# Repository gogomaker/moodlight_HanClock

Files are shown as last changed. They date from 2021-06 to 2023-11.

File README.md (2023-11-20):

# moodlight_HanClock
와디즈에 펀딩되었던 얘쁜 한글시계 따라 만들기

# 제작동기

참 구글이란 게 신기하다. 내가 한글시계 만들겠다고 온 구글(?)에 설쳐 다니다 보니, 와디즈에서 펀딩 진행했었던 아름다운 시계를 뙇 하고 보여주는 것이 아닌가.

나란 사람. 수학적이지만(?) 갬성 있는 사람.

참지 못하고 구매하려 하였으나 파는 곳이 없어 직접 만들기로 한다...

# 제작일기
2021-02-27: 아름다움에 이끌리어 제작을 시작하였다.

2021-04-14: 그 이후로 바뻐서 작업 못 하다가 다시 시작함

2021-06-15: 컴파일 에러 수정 

2021-06-18: 오늘은 LED관련 제어 함수를 생성하였다. 요즘 따라 작업이 아주 잘 된다.

2021-06-19: 오늘은 LED관련 제어 함수를 모두 완성하였다. 
실제로 실행하였을 때는 제대로 동작하지 않는 부분이 있을 것 같다만, 
논리적으로는 없는 것 같다. 또한, 코드 설명 주석을 수정하였고, LED의 delay 를 제외하고는
모두 다 완성하였다.

2021-06-20: 오늘은 프로그램을 완성하였다. 그리고 PCB설계의 엄청난 에러를 수정하였다.
우선, 프로그램은 기존에 있던 코드를 읽기 좋게 다듬고, 몇가지 변수를 추가하고, 코드를 정돈하였다.
또한, PCB설계에서 LED의 극을 잘못 설정해 놓았었기에, 이 또한 수정하였고,
'시' LED의 (-) 극을 digital pin이 아닌 ground로 바로 연결하였다.(이에 맞게 프로그램도 수정하였다)

2021-06-24: 오늘은 내 옛 노트북을 사용할 수 있게 설정한다고 바뻤다. 
오늘, 옛 노트북에 이 프로젝트를 연동시켜 놓았다.
앞으로는, git push뿐 아니라 git pull도 잘 연습할 수 있을 것 같다.

2021-07-15: 오늘은 시계를 어떻게 만들지, 특히 회로에 대한 부분을 전체적으로 점검했다.

2023-11-20: 오랜만에 (무려 2년만에!) 다시 돌아왔다. 
이제 다시 이 시계를 살려보려 한다. \
아마 디자인을 완전히 갈아엎고 시작할 듯 하다.

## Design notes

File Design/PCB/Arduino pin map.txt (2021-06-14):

Arduino pin map

 3 - LED
 4 - hour LED
 5 - LED
 6 - LED
 9 - LED
10 - LED
11 - LED
12 - SW_MIN
13 - SW_HOUR
A0 - brightness_LED

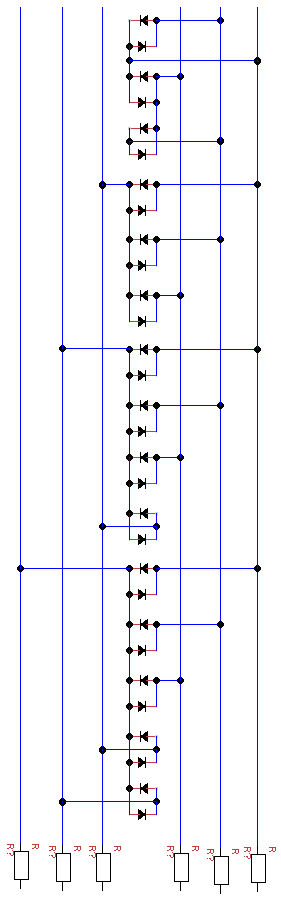
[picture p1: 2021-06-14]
Design/PCB/charie_30pins.png

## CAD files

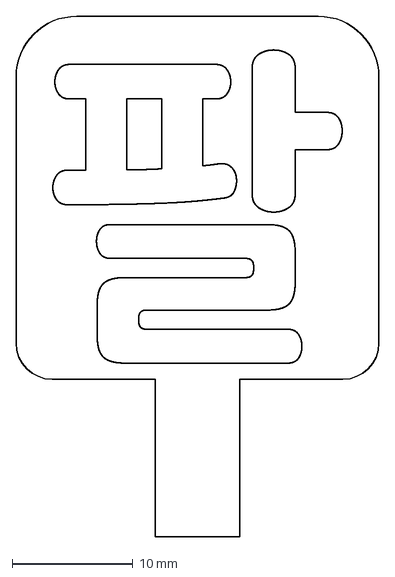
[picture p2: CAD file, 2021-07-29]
Design/External design/acrylic/팔.dxf
30.0 x 43.0 mm

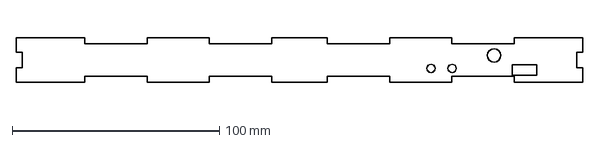
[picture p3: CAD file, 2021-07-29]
Design/External design/back.dxf
273.2 x 21.5 mm

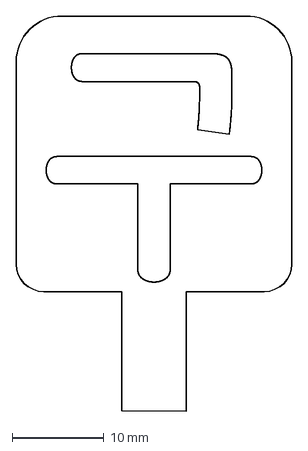
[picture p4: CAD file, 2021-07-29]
Design/External design/acrylic/구.dxf
30.0 x 43.0 mm

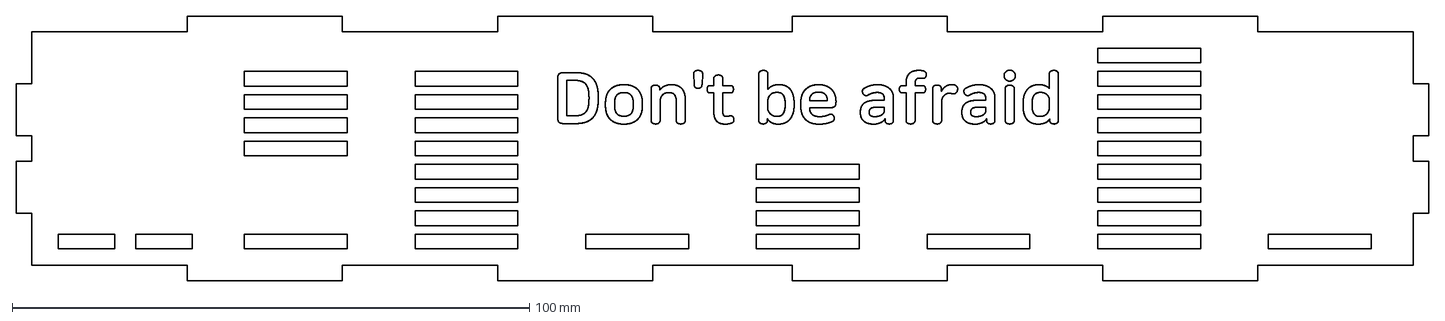
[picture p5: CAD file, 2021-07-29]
Design/External design/top.dxf
273.2 x 51.2 mm

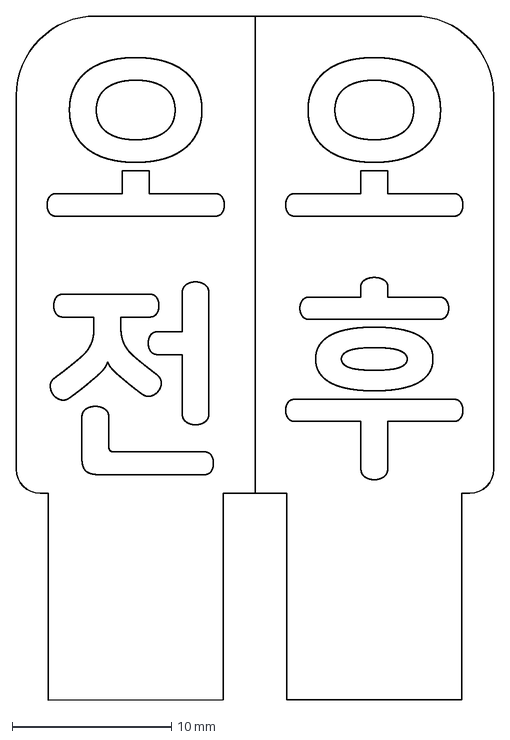
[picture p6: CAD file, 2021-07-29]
Design/External design/acrylic/오전오후.dxf
30.0 x 43.0 mm

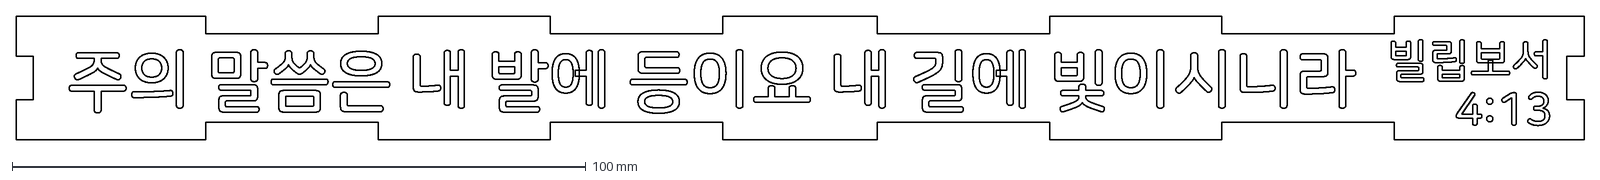
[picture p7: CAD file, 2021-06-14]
Design/External design/front.dxf
273.2 x 21.5 mm

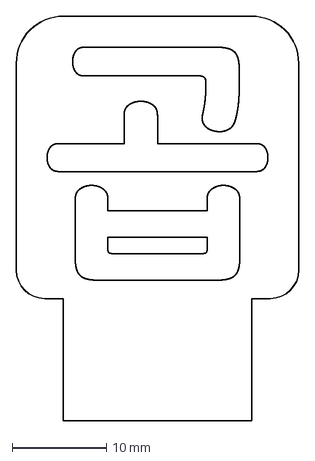
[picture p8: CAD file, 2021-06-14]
Design/External design/acrylic/곱.dxf
30.0 x 43.0 mm

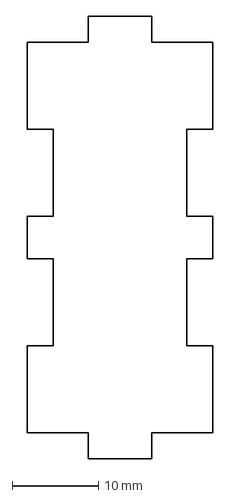
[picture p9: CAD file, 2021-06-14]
Design/External design/side.dxf
21.5 x 51.2 mm

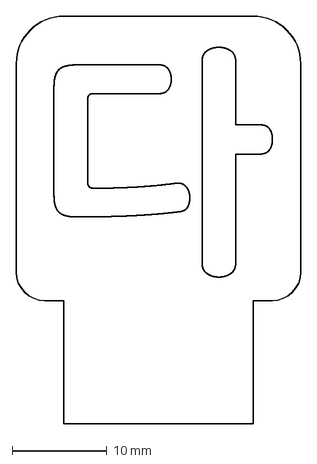
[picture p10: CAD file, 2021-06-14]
Design/External design/acrylic/다.dxf
30.0 x 43.0 mm

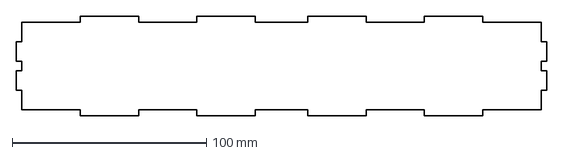
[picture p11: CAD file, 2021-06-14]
Design/External design/base.dxf
273.2 x 51.2 mm

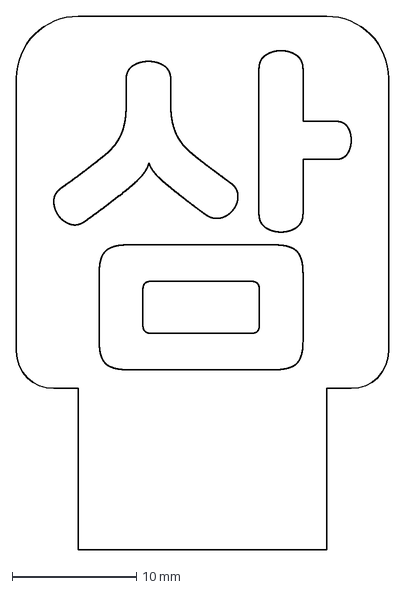
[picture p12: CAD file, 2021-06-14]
Design/External design/acrylic/삼_3.dxf
30.0 x 43.0 mm

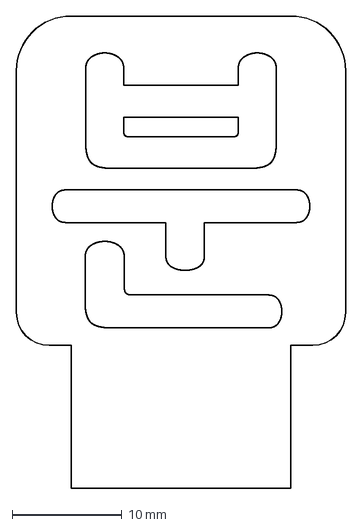
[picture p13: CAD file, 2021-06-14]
Design/External design/acrylic/분.dxf
30.0 x 43.0 mm

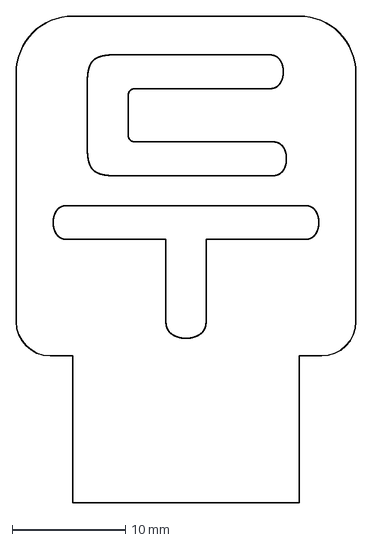
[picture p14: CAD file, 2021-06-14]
Design/External design/acrylic/두.dxf
30.0 x 43.0 mm

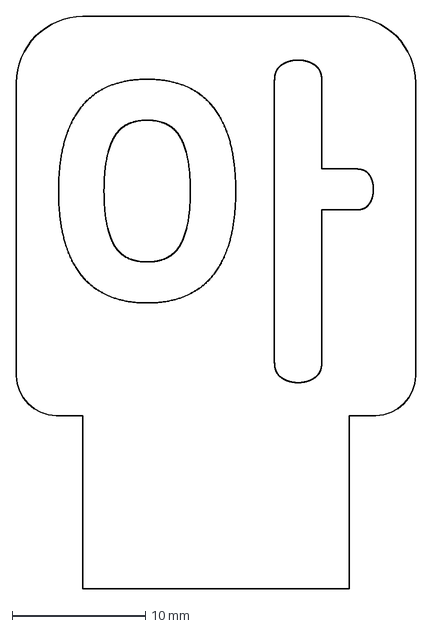
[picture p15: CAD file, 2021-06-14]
Design/External design/acrylic/아.dxf
30.0 x 43.0 mm

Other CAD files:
Design/External design/acrylic/덟.dxf
Design/External design/acrylic/시.dxf
Design/External design/acrylic/삼.dxf
Design/External design/acrylic/한.dxf
Design/External design/acrylic/네.dxf
Design/External design/acrylic/사.dxf
Design/External design/acrylic/사_4.dxf
Design/External design/acrylic/섯.dxf
Design/External design/acrylic/세.dxf
Design/External design/acrylic/십_2.dxf
Design/External design/acrylic/여.dxf
Design/External design/acrylic/열.dxf
Design/External design/acrylic/오.dxf
Design/External design/acrylic/오_2.dxf
Design/External design/acrylic/육.dxf
Design/External design/acrylic/이.dxf
Design/External design/acrylic/이_2.dxf
Design/External design/acrylic/일.dxf
Design/External design/acrylic/일_2.dxf
Design/External design/acrylic/칠.dxf
Design/External design/acrylic/홉.dxf

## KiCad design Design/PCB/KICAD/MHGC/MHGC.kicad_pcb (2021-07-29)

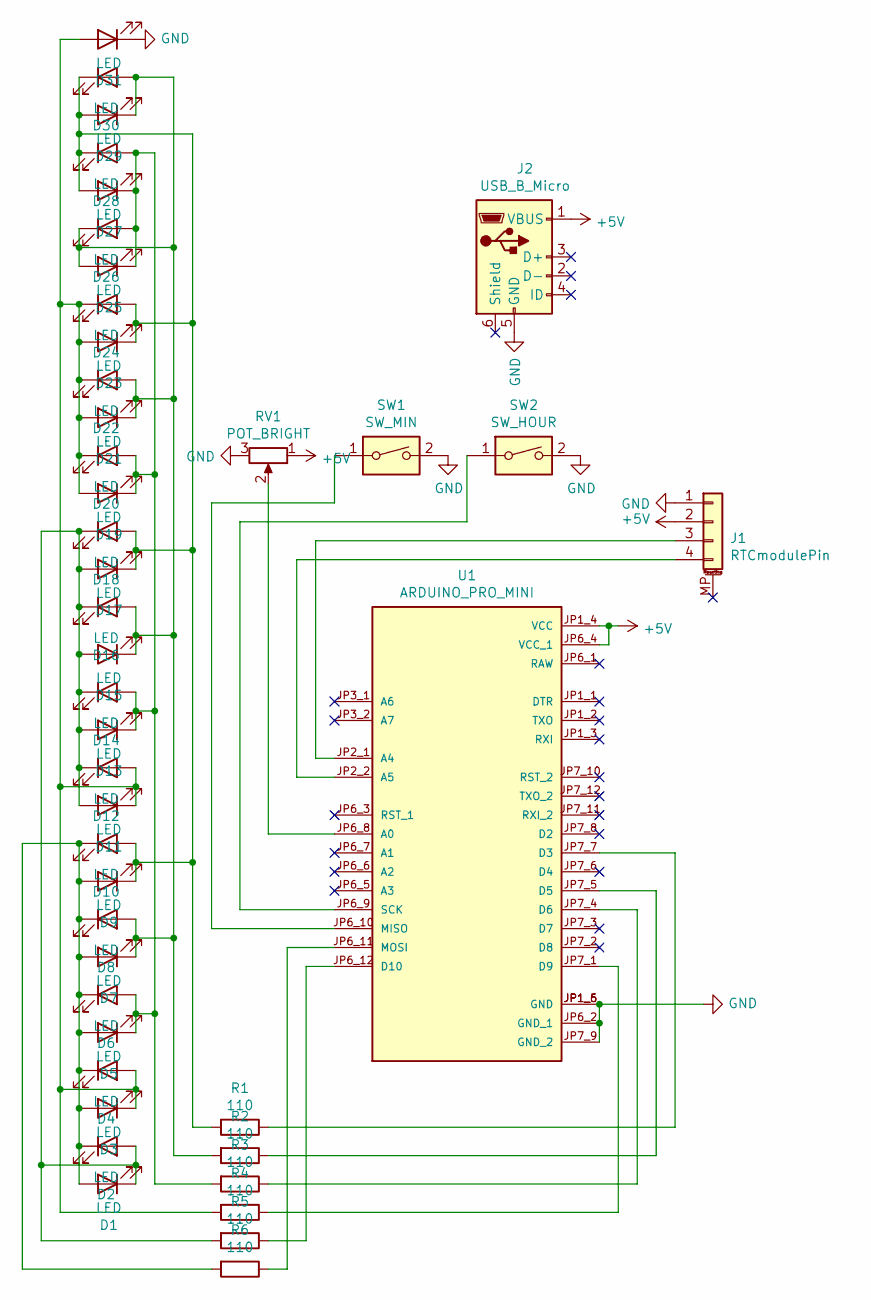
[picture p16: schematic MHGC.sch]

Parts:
D1, D2, D3, D4, D5, D6, D7, D8, D9, D10, D11, D12, D13, D14, D15, D16, D17, D18, D19, D20, D21, D22, D23, D24, D25, D26, D27, D28, D29, D30, D31: LED; 3216LED
J1: RTCmodulePin; PinSocket_1x04_P2.54mm_Vertical
J2: USB_B_Micro; USB_Micro-B_Amphenol_10118194_Horizontal
R1, R2, R3, R4, R5, R6: 110; 3216R
RV1: POT_BRIGHT
SW1: SW_MIN; KLT_SW
SW2: SW_HOUR; KLT_SW
U1: ARDUINO_PRO_MINI; MODULE_ARDUINO_PRO_MINI; PARTREV N/A

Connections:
+5V: J1.2, J2.1 (VBUS), RV1.1, U1.JP1_4 (VCC), U1.JP6_4 (VCC_1)
GND: D31.1 (K), J1.1, J2.5 (GND), RV1.3, SW1.2, SW2.2, U1.JP1_5 (GND), U1.JP1_6 (GND), U1.JP6_2 (GND_1), U1.JP7_9 (GND_2)
unnamed: D1.1 (K), D2.2 (A), D11.2 (A), D12.1 (K), D13.2 (A), D14.1 (K), D15.2 (A), D16.1 (K), D17.2 (A), D18.1 (K), R5.2
unnamed: D1.2 (A), D2.1 (K), D3.2 (A), D4.1 (K), D5.2 (A), D6.1 (K), D7.2 (A), D8.1 (K), D9.2 (A), D10.1 (K), R6.2
unnamed: D9.1 (K), D10.2 (A), D17.1 (K), D18.2 (A), D23.1 (K), D24.2 (A), D27.2 (A), D28.1 (K), D29.2 (A), D30.1 (K), R1.2
unnamed: D3.1 (K), D4.2 (A), D11.1 (K), D12.2 (A), D19.2 (A), D20.1 (K), D21.2 (A), D22.1 (K), D23.2 (A), D24.1 (K), D31.2 (A), R4.2
unnamed: D5.1 (K), D6.2 (A), D13.1 (K), D14.2 (A), D19.1 (K), D20.2 (A), D25.1 (K), D26.2 (A), D27.1 (K), D28.2 (A), R3.2
unnamed: D7.1 (K), D8.2 (A), D15.1 (K), D16.2 (A), D21.1 (K), D22.2 (A), D25.2 (A), D26.1 (K), D29.1 (K), D30.2 (A), R2.2
unnamed: J1.3, U1.JP2_1 (A4)
unnamed: J1.4, U1.JP2_2 (A5)
unnamed: R1.1, U1.JP7_7 (D3)
unnamed: R2.1, U1.JP7_5 (D5)
unnamed: R3.1, U1.JP7_4 (D6)
unnamed: R4.1, U1.JP7_1 (D9)
unnamed: R5.1, U1.JP6_12 (D10)
unnamed: R6.1, U1.JP6_11 (MOSI)
unnamed: RV1.2, U1.JP6_8 (A0)
unnamed: SW1.1, U1.JP6_10 (MISO)
unnamed: SW2.1, U1.JP6_9 (SCK)

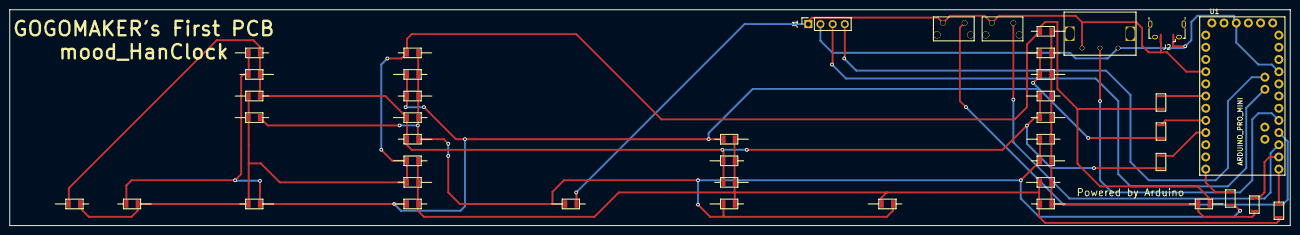
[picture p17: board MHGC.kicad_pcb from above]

Board: 2 copper layers, 267.0 x 45.0 mm, 43 parts (0 on the bottom side), 19 nets.

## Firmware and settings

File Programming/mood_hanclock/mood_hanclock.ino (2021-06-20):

/* mood_hanclock.ino
  Name:   Moodlight_HangeulClock
  Owner:  gogomaker
  Create: 2021-05-14, 5:26 PM

Project introduction_
  This .ino file is very important. Because it's me.

Project TODO

이 프로젝트는, 한글시계 프로그램과 매우 유사하게 제작 될 것이다.
다만 다른 것은 하나, 시간의 표기 방식(사실 날로먹기지 ㅋ)
그렇기에, 기존 한글시계 프로그램의 틀을 거의 가져와서 시간 표시하는 부분만 바꾸면 된다.

수정사안: 
이 시계는 버튼이 2개 들어간다. 그리고 각 버튼이 시간 및 분을 조정하는 데 사용이 된다.
버튼이 길게(1200ms) 눌렸을 때, 시간 또는 분이 증가한다.
또한, 짧은 시간에 대해 처리하는 if문을 날려야 한다.
*/
/* Arduino pin map
  3 - LED
  4 - LED(hour)
  5 - LED
  6 - LED
  9 - LED
 10 - LED
 11 - LED
 12 - SW_MIN
 13 - SW_HOUR
 A0 - brightness_potentiometers

 buttons will connection INPUT_PULLUP.
*/
/* LED pin map
  LED array
  PIN	  0	 1	2	3	4	5
  ARDU	11 10	9	6	5	3
*/

#include "src/functions.h"

//Charlie plexing mapping
byte pair[31][2] = // {LED(+) pin ,LED(-) pin}
{
  {LED_4,LED_5},  //PM
  {LED_5,LED_4},  //AM
  {LED_1,4    },  //hour
  {LED_1,LED_0},  //MIN
  {LED_1,LED_5},  //H_1
  {LED_5,LED_1},  //H_2
  {LED_2,LED_3},  //H_3
  {LED_3,LED_2},  //H_4
  {LED_3,LED_4},  //H_5_F
  {LED_5,LED_3},  //H_6_F
  {LED_3,LED_5},  //H_7_F
  {LED_0,LED_1},  //h_9_F
  {LED_2,LED_4},  //H_5_L
  {LED_2,LED_5},  //H_7_L
  {LED_4,LED_2},  //H_8_L
  {LED_5,LED_2},  //H_9_L
  {LED_4,LED_3},  //H_TEN
  {LED_0,LED_2},  //M_1
  {LED_2,LED_0},  //M_2
  {LED_0,LED_3},  //M_3
  {LED_3,LED_0},  //M_4
  {LED_0,LED_4},  //M_5
  {LED_4,LED_0},  //M_6
  {LED_0,LED_5},  //M_7
  {LED_5,LED_0},  //M_8
  {LED_1,LED_2},  //M_9
  {LED_2,LED_1},  //M_10
  {LED_1,LED_3},  //M_20
  {LED_3,LED_1},  //M_30
  {LED_1,LED_4},  //M_40
  {LED_4,LED_1},  //M_50
};

//declaration variable
extern volatile unsigned long timer0_millis; //millis 오버플로우 대비 초기화
unsigned long time = 0;
byte sec, lastSec = 0;
byte hourPlus, minPlus = 0; //버튼이 눌릴 때 이곳에 값이 임시저장 됨
byte minRtc, hourRtc = 0; //RTC의 시간값이 저장됨
byte min, hour = 0;   //최종적으로 출력되는 시간값이 저장됨
bool isResetMillis = false;
byte bright = 0;  //255가 최대, 0이 최소, 가변저항 제어

byte tMSB, tLSB;  //RTC온도관련
float temp3231;

unsigned long bu_led_w = 0;
bool ledCheck = false;

bool bu_reading[2] = { HIGH, HIGH };  //버튼의 실제 상태를 표현하는 변수
bool bu_state[2] = { HIGH, HIGH };  //체터링을 거른 버튼의 상태를 표현하는 변수
bool last_bu_state[2] = { HIGH, HIGH }; //마지막 버튼 상태
unsigned long LastDebounceTime[2] = {0, 0};

unsigned long bu_t_w, last_bu_t_w = 0;  //시 버튼이 언제 눌렸는가
unsigned long bu_m_w, last_bu_m_w = 0;  //분 버튼이 언제 눌렸는가
unsigned long wait_t, wait_m = 0; //LED깜박일 때 사용
bool isblinkH, isblinkM = false;

void setup() {
  Serial.begin(115200);
  Serial.println("Mood Light Hangeul Clock is turning ON");
  Serial.println("Clock start");
  //bright setting
  bright = map(analogRead(CONTROL_BRIGHT), 0, 1023, 0, BRIGHT_LIMIT);
  //button setting
  pinMode(BU_MIN, INPUT_PULLUP);
  pinMode(BU_HOUR, INPUT_PULLUP);
  //LED pins setting
  pinMode(LED_0, OUTPUT);
  pinMode(LED_1, OUTPUT);
  pinMode(LED_2, OUTPUT);
  pinMode(LED_3, OUTPUT);
  pinMode(LED_4, OUTPUT);
  pinMode(LED_5, OUTPUT);
}

void loop() {
  time = millis();
  bright = map(analogRead(CONTROL_BRIGHT), 0, 1023, 0, BRIGHT_LIMIT);
  get3231Date();
  if (!sec && !minRtc && !hourRtc) {	//millis 초기화
		if(!timer0_millis) isResetMillis = true;
		if (isResetMillis == true) {
			//Serial.println("Timer reset");
			bu_led_w = 0;
			LastDebounceTime[0] = 0;
			LastDebounceTime[1] = 0;
			bu_t_w = 0;
			last_bu_t_w = 0;
			wait_t = 0;
			wait_m = 0;
			time = 0;
			timer0_millis = 0;
			isResetMillis = false;
		}
	}
  
  //매 초마다
  if (sec != lastSec) {
    hour = (hourRtc + hourPlus) % 24;
    min = (minRtc + minPlus) % 60;
    if (!sec) {	//매 0초마다(1분 간격으로)
      if (hourPlus || minPlus) {  //RTC값 동기화
      //Serial.println("RTC set");
      set3231Date();
      }
      //Serial.println("updated");
    }
    lastSec = sec;
  }
  displayTime(hour, min); //시간출력, 계속 돌려야 하기에 loop에 넣었다
  
  //button
  void changeHour();
  void changeMin();
}

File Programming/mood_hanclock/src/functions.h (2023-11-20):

#ifndef __FUNCTIONS_H__
# define __FUNCTIONS_H__

#include <Arduino.h>
#include <Wire.h>

//define pin map
#define LED_0 11
#define LED_1 10
#define LED_2 9
#define LED_3 6
#define LED_4 5   
#define LED_5 3
#define BU_MIN 12
#define BU_HOUR 13
#define CONTROL_BRIGHT A0
//define LED numbers
#define LED_PM 0
#define LED_AM 1
#define LED_HOUR 2
#define LED_MIN 3
#define LED_H_1 4
#define LED_H_2 5
#define LED_H_3 6
#define LED_H_4 7
#define LED_H_5_F 8
#define LED_H_6_F 9
#define LED_H_7_F 10
#define LED_H_8_F 9
#define LED_H_9_F 11
#define LED_H_5_L 12
#define LED_H_6_L 12
#define LED_H_7_L 13
#define LED_H_8_L 14
#define LED_H_9_L 15
#define LED_H_TEN 16
#define LED_M_1 17
#define LED_M_2 18
#define LED_M_3 19
#define LED_M_4 20
#define LED_M_5 21
#define LED_M_6 22
#define LED_M_7 23
#define LED_M_8 24
#define LED_M_9 25
#define LED_M_10 26
#define LED_M_20 27
#define LED_M_30 28
#define LED_M_40 29
#define LED_M_50 30
//define other...
#define DS3231_I2C_ADDRESS 104
#define FLICKER_TIME 5  //LED flicker ms
#define debounceDelay 50  //button debounce removal delay
#define bu_interval 1200
#define BRIGHT_LIMIT 250
#define LED_DELAY 2

extern byte pair[31][2];
extern unsigned long time;
extern byte sec, lastSec;
extern byte hourPlus, minPlus; //버튼이 눌릴 때 이곳에 값이 임시저장 됨
extern byte minRtc, hourRtc; //RTC의 시간값이 저장됨
extern byte min, hour;   //최종적으로 출력되는 시간값이 저장됨
extern bool isResetMillis;
extern byte bright;  //255가 최대, 0이 최소, 가변저항 제어
extern byte tMSB, tLSB;  //RTC온도관련
extern float temp3231;
extern bool bu_reading[2];  //버튼의 실제 상태를 표현하는 변수
extern bool bu_state[2];  //체터링을 거른 버튼의 상태를 표현하는 변수
extern bool last_bu_state[2]; //마지막 버튼 상태
extern unsigned long LastDebounceTime[2];
extern unsigned long bu_t_w, last_bu_t_w;  //시 버튼이 언제 눌렸는가
extern unsigned long bu_m_w, last_bu_m_w;  //분 버튼이 언제 눌렸는가

void clearLED();
int turnOnLED(int n);
int displayTime(int h, int m);
void changeHour();
void changeMin();
byte decToBcd(byte val);
void set3231Date();
void get3231Date();
float get3231Temp();
void showSerialTime();

#endif

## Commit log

2021-06-14 Headerfile complited 헤더파일을 완성하였고, 일단 보이는 모든 에러를 잡았다.
2021-06-15 Solve comfile error 전 커밋에서는 구문 오류는 없었지만 스케치를 컴파일하면 자꾸 에러가 났었다. 해당 문제의 원인이 c_cpp_properties.json이라는 것을 알고 수정하여서 오류를 해결하였다.
    [MHGC.DSN]
2021-06-15 Make button function 버튼 함수를 만들 수 있게 코드 정리하고, 사용하지 않는 변수를 정리하였으며, main루프의 기본 코드도 삽입하였다
    [MHGC.DSN]
2021-06-16 complete button function
2021-06-18 LED control function created LED를 제어하는 함수를 만들었다. displayTime라는 함수를 호출하면, 해당 함수가 turnOnLED함수를 실행시켜서 켜려는 LED핀의 상태를 LED가 켤 수 있게 되도록 한다. 다만, 아직 미흡한 부분이 있어 추가적 보수가 많이 필요하다.
    [MHGC.DSN]
2021-06-19 Almost make LED control function LED제어 함수를 거의 다 만들었다. 그러나, 제대로 작동하는지에 대한 의문점이 있고, delay코드는 delayMicroseconds로 바꾸거나 millis를 활용하는 코드로 변경해야 한다. 조만간 이 코드를 시뮬레이션 해 보아야 겠다.
2021-06-20 Complete programming 프로그램의 에러도 다 잡고, 기능도 다 구현했다. 내가 코드만 보기에는 전혀 문제가 없어 보인다. 이제 남은 것은 PCB에 부품들을 조립하여 하드웨어에 이 코드를 업로드 후 테스트 하는 것 뿐... 부디 내가 만든 코드가 문제가 없는 것이길 바란다.
    [MHGC.DSN]
2021-07-17 Restarted PCB design 오늘 나는 PCB작업프로그램을 OrCAD에서 KiCAD로 바꿨다
    [MHGC.DSN, MHGC.kicad_pcb, MHGC.sch]
2021-07-19 Started PCB design 드디어 PCB에 부품 배치를 시작했다
    [MHGC.kicad_pcb, MHGC.sch]
2021-07-22 Completed PCB design
    [MHGC.kicad_pcb, MHGC.sch]
2021-07-29 Change design files 디자인 파일 중에서, PCB설계에 맞추어 버튼 및 기타 부품이 배치될 공간을 작업하고, 아크릴 관련 공차 설정도 다시 하였다.
    [MHGC.kicad_pcb, MHGC.sch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]
2023-11-20 Project-Restart 프로젝트 재정비하고, 다시 시작하기 위한 깃 세팅을 하였다.
